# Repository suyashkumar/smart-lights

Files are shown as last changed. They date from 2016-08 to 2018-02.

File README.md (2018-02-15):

# smart-lights
This project is a hassle-free cloud connected lighting system that interfaces with standard light switches via a 3D printed lightswitch cover with a built-in servo mount (see `3DModels/` for STL and OpenSCAD code). 

This project uses an ESP8266 WiFi microcontroller along with my [conduit](https://github.com/suyashkumar/conduit) IoT service/library to expose switching functionality that can be called via a RESTful API from anywhere in the world!

The whole stack for this project--including firmware, hardware, server (see my [conduit](https://github.com/suyashkumar/conduit) repo), client web appliction, and physical 3D printed components were designed and built from the ground up. 

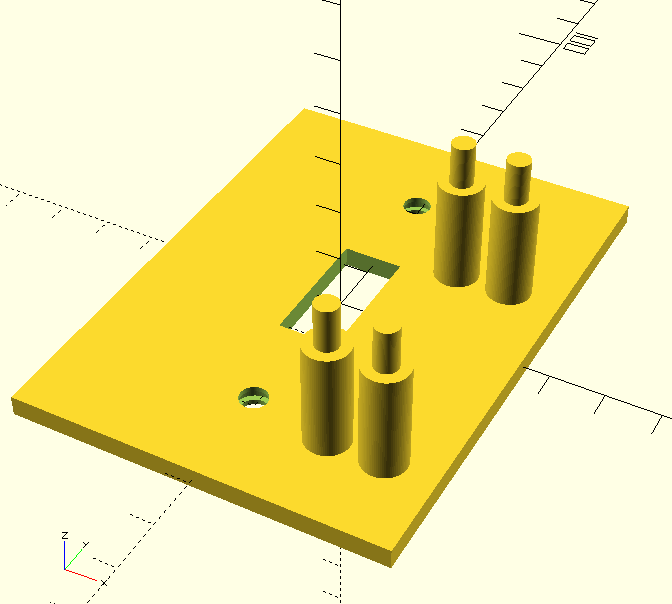
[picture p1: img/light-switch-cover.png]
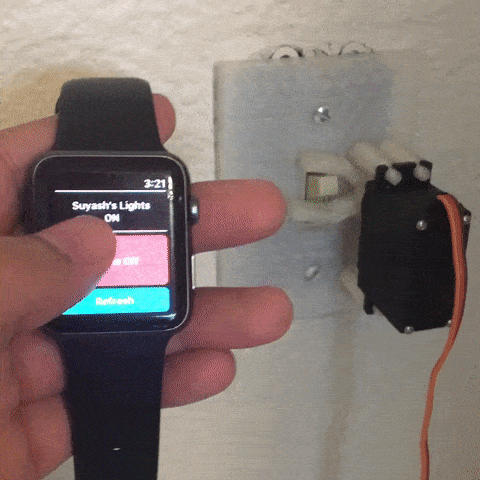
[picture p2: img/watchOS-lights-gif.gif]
 
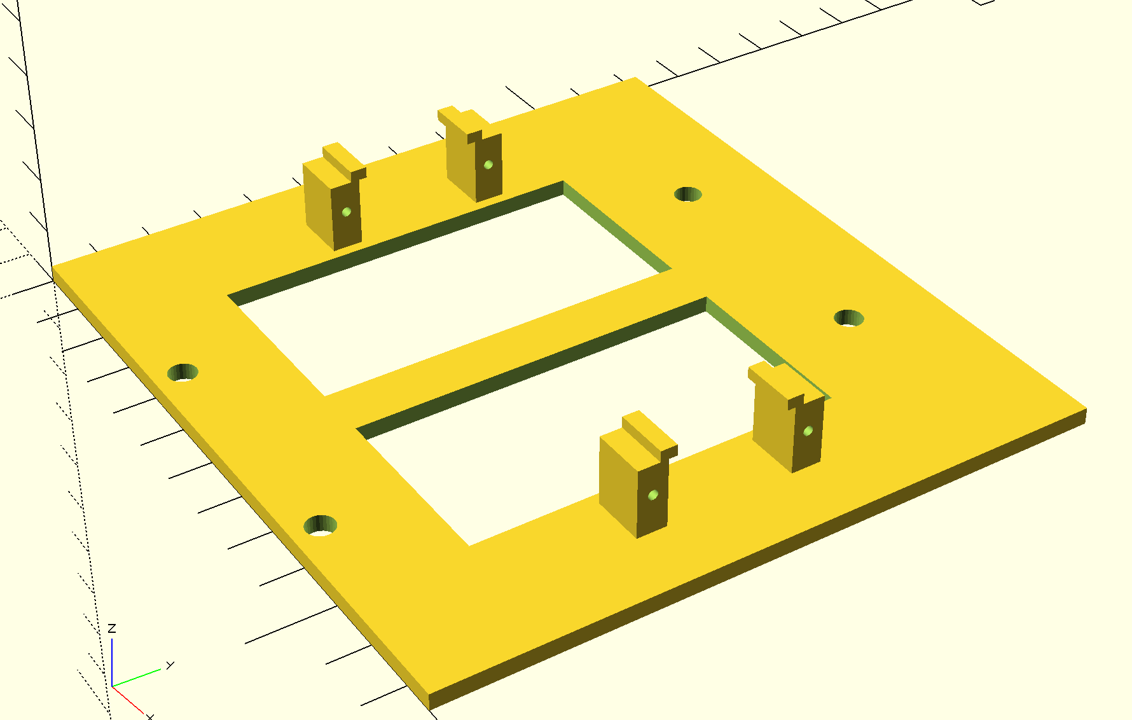
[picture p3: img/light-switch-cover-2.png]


## Structure

- `3DModels/`: OpenSCAD code for lightswitch cover
- `firmware/`: Firmware for the ESP8266 microcontroller
- `web/`: ReactJS web interface to interact with [conduit](https://github.com/suyashkumar/conduit) to call functions & get data from the ESP8266 chip

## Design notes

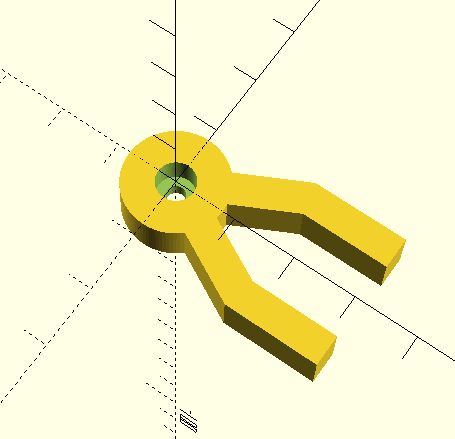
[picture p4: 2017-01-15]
img/servo-mount-prongs.png

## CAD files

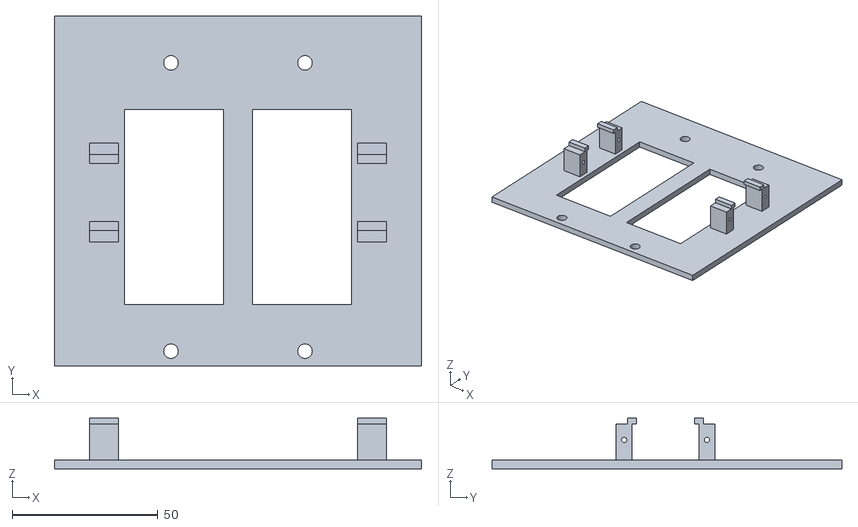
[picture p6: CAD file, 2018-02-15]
3DModels/light-switch-cover-flat-switches.stl
126.0 x 120.0 x 17.5

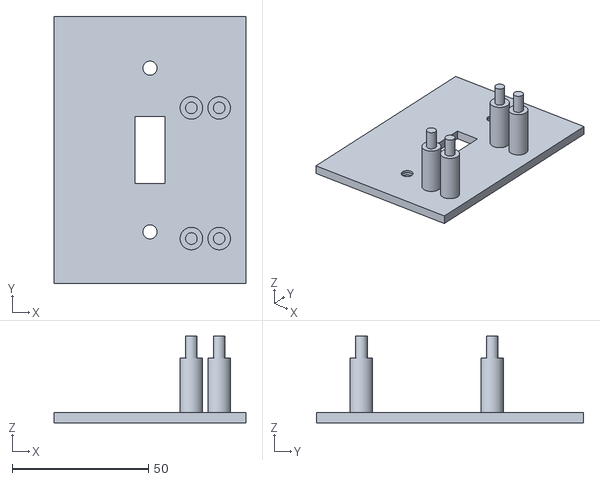
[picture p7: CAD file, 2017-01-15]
3DModels/light-switch-cover.stl
70.4 x 98.0 x 31.9

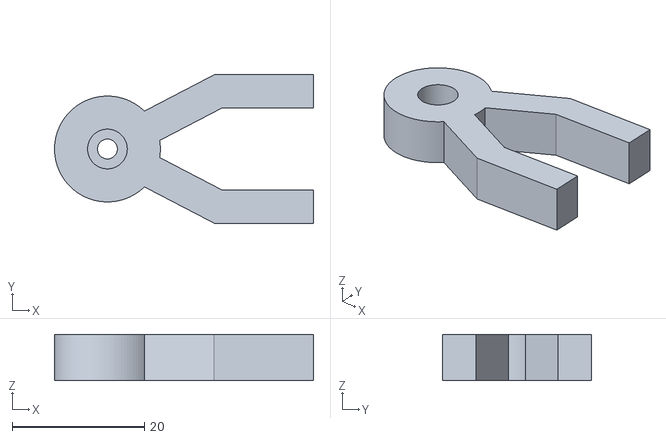
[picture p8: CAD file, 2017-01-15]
3DModels/servo-mount.stl
39.1 x 22.4 x 7.00

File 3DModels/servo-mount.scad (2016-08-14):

servoInnerDiameter = 6;
extensionLength = 11.0;
screwDiameter = 3;
barWidth = 5;
barAngle = 55;
armLength = 15;
componentHeight = 7;
$fn = 100;
module servoMount(){
    difference(){
        cylinder(d=servoInnerDiameter+10, h=componentHeight);
        cylinder(d=servoInnerDiameter, h=componentHeight/1.5);
        cylinder(d=screwDiameter, h=componentHeight);
    }
}
module armBase(){
    rotate([0,0,-barAngle/2])translate([(servoInnerDiameter+1)/2,-barWidth/2,0]) union(){
    cube([extensionLength+5, barWidth, componentHeight]);
        translate([extensionLength+5,0,0])rotate([0,0,barAngle/2])cube([armLength, barWidth, componentHeight]);
    }
}
module arms(armType=0){
   union(){
       armBase();
       mirror([0,1,0])armBase();
   }
}
module drawAll(){
    union(){
        servoMount();
        arms();

    }
}
rotate([180,0,0])
drawAll();

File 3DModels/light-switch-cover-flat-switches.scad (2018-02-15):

use <scad_modules/servo_clip_with_screws.scad>;
// 41
$fn = 30;
base_width = 65;
base_length = 120; 
base_depth = 3;

cutout_x = 24;
cutout_y = 21;
cutout_width = 34;
cutout_height = 67;

screw_x = 40;
screw_1_y = cutout_y-16;
screw_2_y = cutout_y + cutout_height + 16;
screw_dia = 5;

module face_plate() {
    difference() {
        cube([base_width, base_length, base_depth]);
        translate([cutout_x, cutout_y, 0])cube([cutout_width, cutout_height, base_depth]);
        translate([screw_x, screw_1_y, base_depth/2])cylinder(d=screw_dia, h=base_depth, center=true);
        translate([screw_x, screw_2_y, base_depth/2])cylinder(d=screw_dia, h=base_depth, center=true);
    }
}

module half_light_switch() {
    union() {
        face_plate();
        translate([22, cutout_y + 21 + 4.5 , 1])rotate([0,0,90])servo_clip();
    }
}

half_light_switch();
translate([2*base_width, 0, 0])mirror([1, 0, 0])half_light_switch();

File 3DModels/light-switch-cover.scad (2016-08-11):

holeDia = 6.15;
baseThickness = 3.8;
wellDepth = baseThickness/2;
servoStrutDia = 4.28;
servoStrutHeightOffset = 22;
servoStrutHeight = 30;
bottomStrutOffset = 32.5;
inlineServoStrutSep = 10.21;
servoWidth = 20.4;
servoStrutsX = 5;
$fn = 80;

module base(){
    difference(){
        cube([70.36, 98, baseThickness], center=true);
        cube([11,24.5, baseThickness+2],center=true);
        translate([0,30.05,(baseThickness/2 - wellDepth)])cylinder(r=(holeDia+1)/2, h=wellDepth, center=true);
        translate([0,30.05,0])cylinder(r=(holeDia-1)/2, h=baseThickness, center=true);
        translate([0,-30.05, (baseThickness/2 - wellDepth)])cylinder(r=(holeDia+1)/2, h=wellDepth, center=true);
        translate([0,-30.05,0])cylinder(r=(holeDia-1)/2, h=baseThickness, center=true);
    }
}

module servoStrut(){
    union(){
        cylinder(d=servoStrutDia, h=servoStrutHeight);
        cylinder(d=(servoStrutDia+4), h=servoStrutHeightOffset);
    }
    
}

module servoStruts(){
    translate([servoWidth+servoStrutsX,-bottomStrutOffset,0])servoStrut();
    translate([servoWidth+servoStrutsX-inlineServoStrutSep,-bottomStrutOffset,0])servoStrut();
    translate([servoWidth+servoStrutsX,-bottomStrutOffset+43.68+servoStrutDia,0])servoStrut();   
    translate([servoWidth+servoStrutsX-inlineServoStrutSep,-bottomStrutOffset+43.68+servoStrutDia,0])servoStrut();  
}

module drawAll(){
    union(){
        base();
        servoStruts();
    }
}

drawAll();

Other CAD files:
3DModels/servoMount_arms_flip.stl

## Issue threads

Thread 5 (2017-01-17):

Enquiry

mcat-ee, 2017-01-17:
Hey!

Is there a feedback mechanism for if the switch is manually toggled? Or will the previous toggle state of the switch persist in the smart-light's state machine?

suyashkumar, 2017-01-18:
Currently there is no feedback, however a feedback system using a potentiometer coupled to the axis of rotation should be able to serve that purpose!

Currently the servo power is turned off when it's not moving, allowing the servo to move more "freely" but it's still not recommended to move it around much :).

Closed 2017-02-08.

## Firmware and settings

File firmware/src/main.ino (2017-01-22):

#include <Arduino.h> 
// #include <wifi_info.h> 
#include <Conduit.h>
#include <Servo.h>

#define LED 4
#define servo D6
#define servo_power D5
#define OFF_STATUS 0
#define ON_STATUS 1
#define LIGHTS_ON_ANGLE 65
#define LIGHTS_OFF_ANGLE 25

// Fill out the below Github peeps:
const char* ssid = "mywifi";
const char* password = "";
const char* deviceName = "suyash";
const char* apiKey = "your-api-key-here";
const char* serverUrl = "conduit.suyash.io"; 

Conduit conduit(deviceName, serverUrl, apiKey); // init Conduit 

// Global state
int ledStatus = OFF_STATUS; 
int lightsStatus = ON_STATUS; 

Servo servo1; 

// Toggle attached signal LED
int ledToggle(){
  digitalWrite(LED, (ledStatus) ? LOW : HIGH);
  ledStatus = (ledStatus) ? OFF_STATUS : ON_STATUS;
  Serial.println("Toggled");
  conduit.publishMessage((ledStatus) ? "LED ON" : "LED OFF");
}

// Get a sanity check message (to check conduit communication)
int publishMessage(){
    conduit.publishMessage("hey there, things are working");
}

// Turn lights on
int lightsOn(){
	digitalWrite(servo_power, HIGH);
	servo1.write(LIGHTS_ON_ANGLE);
	delay(500);
	conduit.publishMessage("ON");
	digitalWrite(servo_power, LOW);
	lightsStatus = ON_STATUS;
}

// Turn lights off
int lightsOff(){
	digitalWrite(servo_power, HIGH);
	servo1.write(LIGHTS_OFF_ANGLE);
	delay(500); 
	conduit.publishMessage("OFF");
	digitalWrite(servo_power, LOW);
	lightsStatus = OFF_STATUS;
}

int lightsStatusFunc(){
	conduit.publishMessage((lightsStatus) ? "ON" : "OFF"); 
}

int lightsToggle() {
	(lightsStatus) ? lightsOff() : lightsOn();
}

void setup(void){
  Serial.begin(115200); // Start serial
  pinMode(LED, OUTPUT); // Set LED pin to output
  pinMode(servo, OUTPUT); // Set up servo output
  pinMode(servo_power, OUTPUT); 
  
  // Servo initialization
  digitalWrite(servo_power, HIGH); 
  servo1.attach(servo); 
  servo1.write(LIGHTS_ON_ANGLE);
  delay(500);
  digitalWrite(servo_power, LOW); 

  // Conduit initialization  
  conduit.startWIFI(ssid, password); // Config/start wifi
  conduit.init();

  // Conduit bindings
  conduit.addHandler("ledToggle", &ledToggle);
  conduit.addHandler("hello", &publishMessage); 
  conduit.addHandler("lightsOn", &lightsOn);
  conduit.addHandler("lightsOff", &lightsOff);
  conduit.addHandler("lightsStatus", &lightsStatusFunc); 
  conduit.addHandler("lightsToggle", &lightsToggle); 

}

void loop(void){
  conduit.handle(); 
}

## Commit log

2016-08-11 Inital Commit
    [light-switch-cover-large.stl, light-switch-cover-struts.stl, light-switch-cover.scad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]
2016-08-11 Slight Height Changes
    [light-switch-cover.scad]
2016-08-11 Added servo mount
    [servoMount.scad, servoMount.stl]
2016-08-11 Servo mount now has arms, wider attach diameter
    [servoMount.scad, servoMount_arms.stl]
2016-08-14 New dir structure
    [light-switch-cover-large.stl, light-switch-cover-struts.stl, light-switch-cover.scad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]
2016-08-14 Working smart light switch
2017-01-15 3DModels cleanup
    [light-switch-cover-large.stl, light-switch-cover-struts.stl, light-switch-cover.stl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]
2018-02-12 Configure deployment via GitHub pages, update device name
2018-02-15 Add new lightswitch covers for flat switches
    [light-switch-cover-flat-switches.scad, light-switch-cover-flat-switches.stl]
